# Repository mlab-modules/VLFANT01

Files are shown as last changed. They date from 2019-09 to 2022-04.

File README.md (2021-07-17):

<!--- Name:VLFANT01B: --->
# VLFANT01B
<!--- LongName --->
## VLF antenna interconnection module
<!--- ELongName --->

<!--- Lead --->

<!--- ELead --->

The module is usually used to make a magnetic loop antenna from the UTP pigtail. It is basic antenna for [VLF ionospheric monitoring station](https://github.com/Ionozor/VLFMON01).

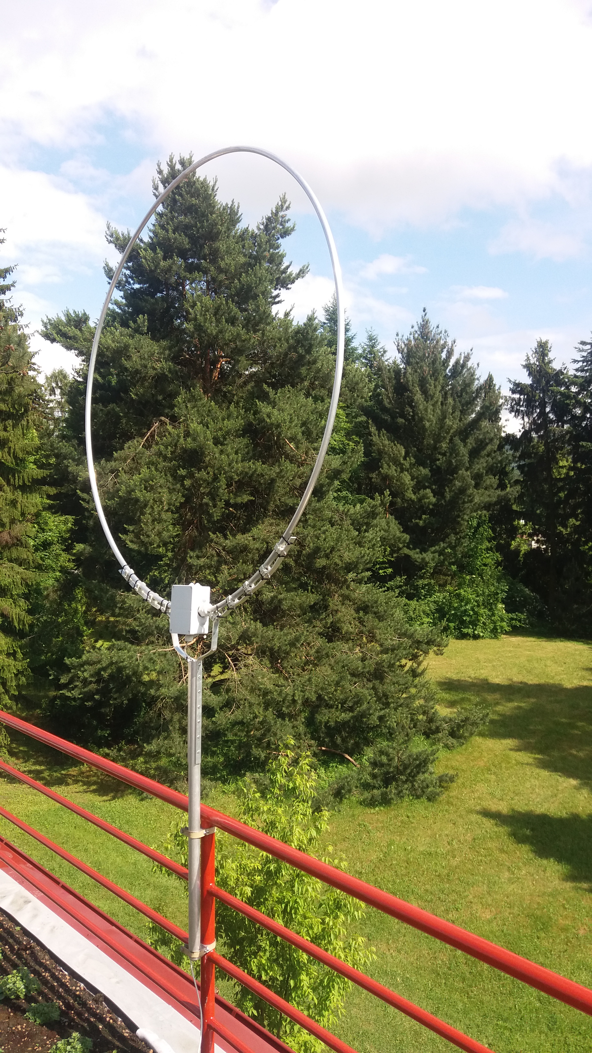
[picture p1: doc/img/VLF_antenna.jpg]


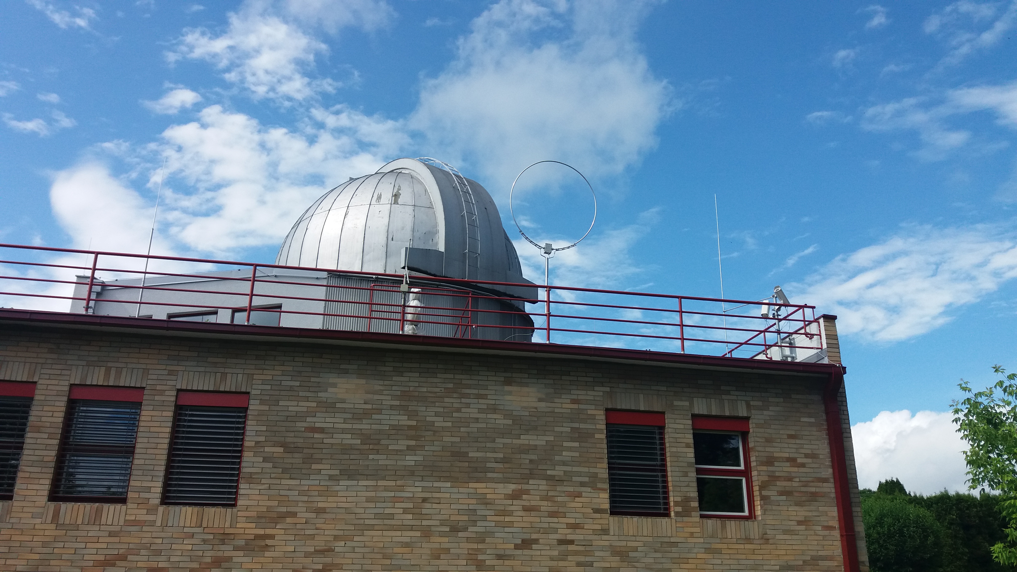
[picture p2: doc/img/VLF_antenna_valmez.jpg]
VLF antenna mounted on Valasske Mezirici observatory


<!--- Description --->
<!--- EDescription --->
<!--- Content --->

## Hardware

The module could be used by multiple ways

### Antenna feed end on MLAB board

This usage case uses only one RJ45 connector populated on board. This connector is used for connection the UTP feed from the antenna.

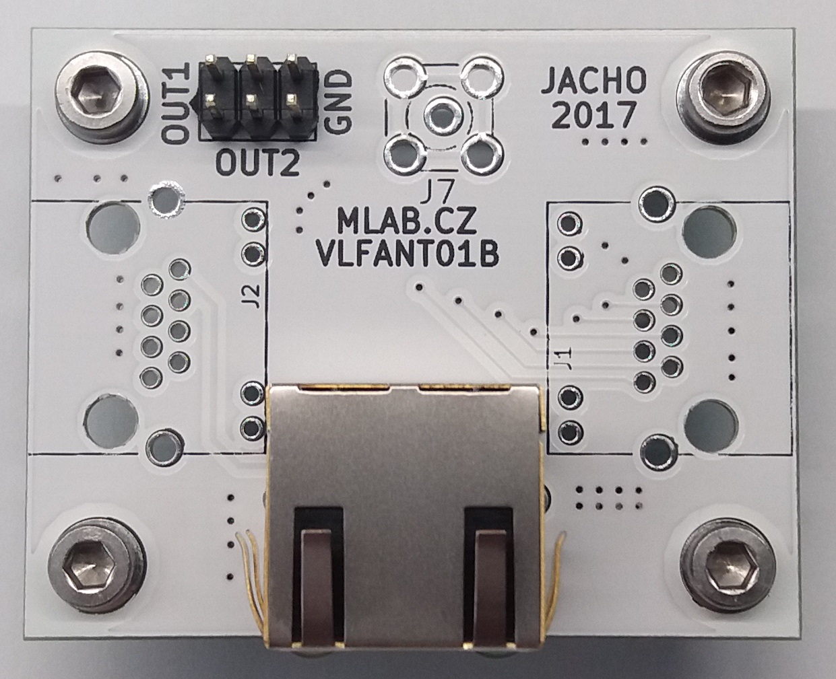
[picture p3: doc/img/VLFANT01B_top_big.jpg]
VLFANT01B


### Antenna connection module

In that situation all three RJ45 connectors are populated on the board. The two are used for connection the antenna loop. The last is used for feeding the signal to the receiver unit.

## VLF antenna construction

The antenna is made from an aluminium tube ring. The parameters of the aluminium tube are not critical. But it is practical to use an tube which allows direct insertion of UTP pigtail including the connectors.
The circumference of the tube ring should match the lengh of UTP cable used. Therefore the example 1.5m circle diameter aproximately match to 5m lenght UTP cable pigtail. In the reality we used the STP (Shilded variant of UTP cable), to minimize possibility of differences between antennas by different shaping of the cable in the tube, which could alter overall capacity, resulting in different resonant frequency. 

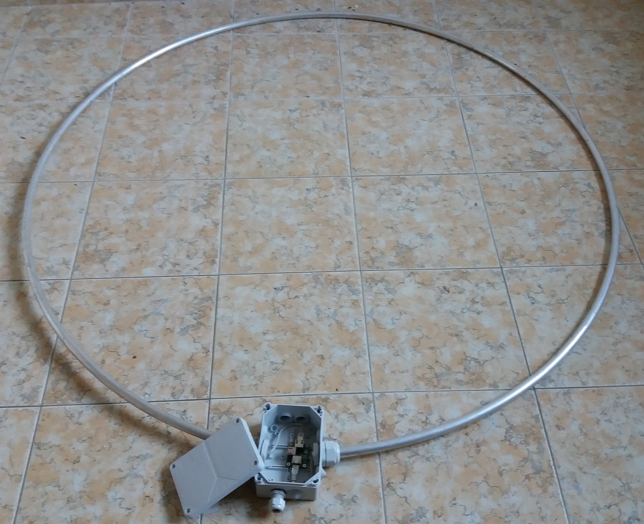
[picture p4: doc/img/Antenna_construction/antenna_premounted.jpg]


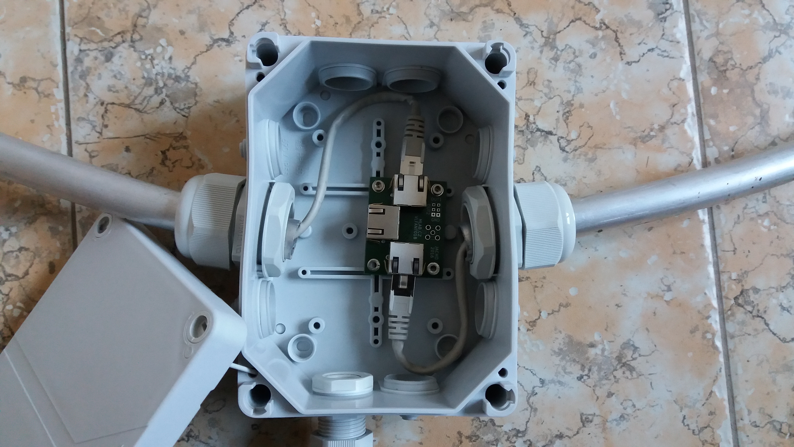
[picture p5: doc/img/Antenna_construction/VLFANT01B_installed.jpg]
VLFANT01B


<!--- EContent --->
<sub><sup> Generated with [MLABweb](https://github.com/MLAB-project/MLABweb). (2019-09-12)</sup></sub>

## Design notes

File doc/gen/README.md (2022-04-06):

# PCB

Board size: 50.29x40.13 mm (1.98x1.58 inches)

- This is the size of the rectangle that contains the board
- Thickness: 1.6 mm (63 mils)
- Material: FR4
- Finish: HAL
- Layers: 2
- Copper thickness: 35 µm

Solder mask: TOP / BOTTOM

- Color: Green

Silk screen: TOP / BOTTOM

- Color: White

# Important sizes

Clearance: 0.2 mm (8 mils)

Track width: 0.2 mm (8 mils)

- By design rules: 0.2 mm (8 mils)

Drill: 0.4 mm (16 mils)

- Vias: 0.4 mm (16 mils) [Design: 0.3 mm (12 mils)]
- Pads: 0.89 mm (35 mils)

Via: 0.8/0.4 mm (31/16 mils)

- By design rules: 0.4/0.3 mm (16/12 mils)
- Micro via: no [0.2/0.1 mm (8/4 mils)]
- Burried/blind via: no

Outer Annular Ring: 0.37 mm (15 mils)

- By design rules: 0.37 mm (15 mils)

Eurocircuits class: 4C

# General stats

Components count: (SMD/THT)

- Top: 0/9 (THT)
- Bottom: 0/0 (NONE)

Defined tracks:

- 0.3 mm (12 mils)
- 0.5 mm (20 mils)
- 0.8 mm (31 mils)
- 0.9 mm (35 mils)
- 1.0 mm (39 mils)
- 1.2 mm (47 mils)
- 1.5 mm (59 mils)
- 2.0 mm (79 mils)

Used tracks:

- 0.2 mm (8 mils) (75) defined: no
- 0.3 mm (12 mils) (37) defined: yes
- 0.5 mm (20 mils) (39) defined: yes

Defined vias:

Used vias:

- 0.8/0.4 mm (31/16 mils) (Count: 47, Aspect: 2.0 A) defined: no

Holes (excluding vias):

- 0.89 mm (35 mils) (6)
- 0.93 mm (37 mils) (36)
- 1.5 mm (59 mils) (1)
- 1.65 mm (65 mils) (6)
- 1.7 mm (67 mils) (4)
- 3.0 mm (118 mils) (4)
- 3.3 mm (130 mils) (6)

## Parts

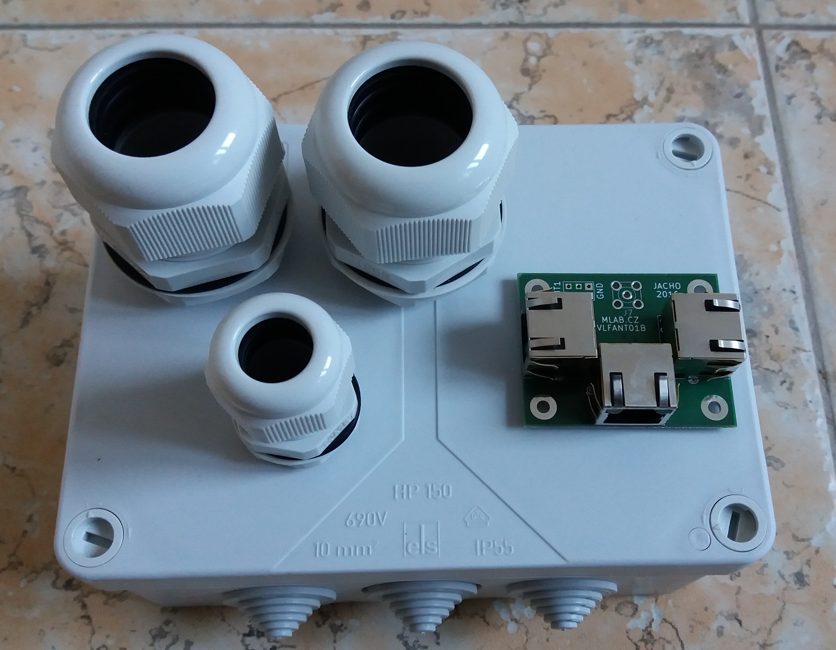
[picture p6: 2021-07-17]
doc/img/Antenna_construction/box_material.jpg

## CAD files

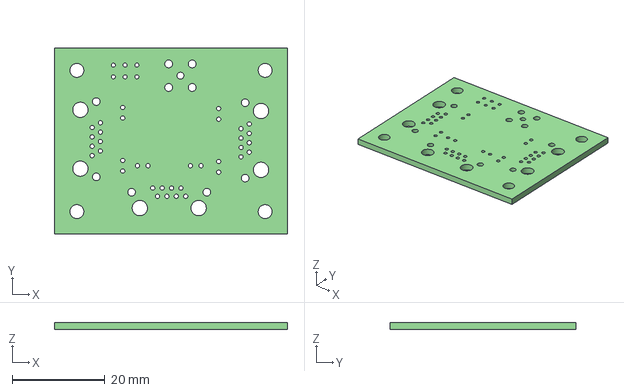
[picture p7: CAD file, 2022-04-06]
doc/gen/VLFANT01B.step
50.3 x 40.1 x 1.60 mm

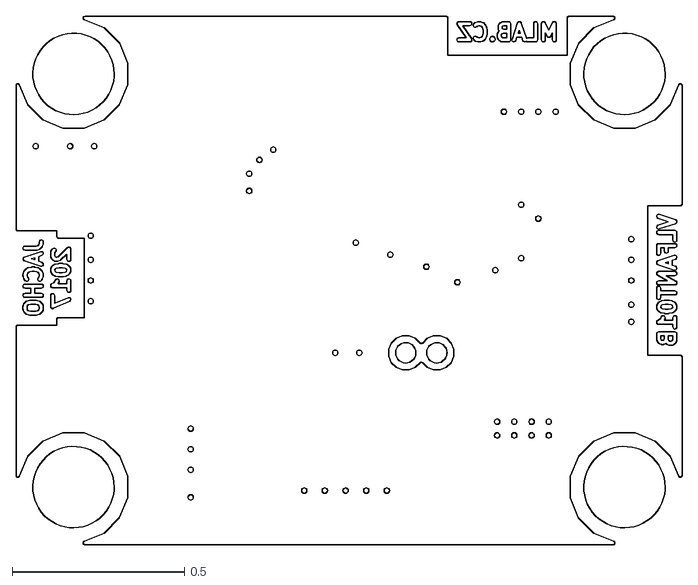
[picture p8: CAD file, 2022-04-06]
doc/gen/dxf/VLFANT01B-B_Cu.dxf
1.93 x 1.53

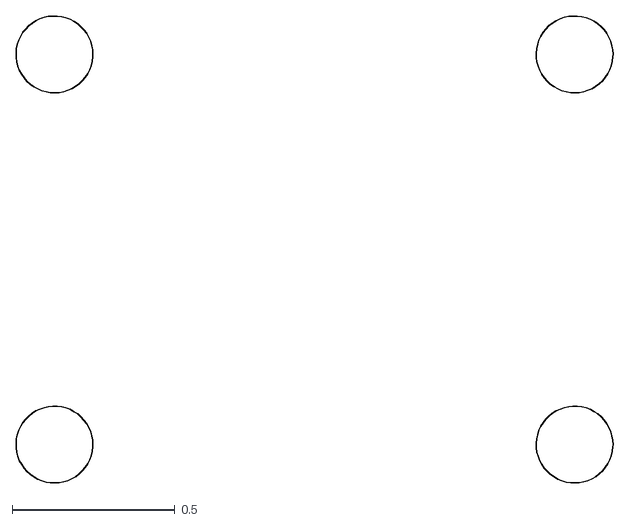
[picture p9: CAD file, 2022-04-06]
doc/gen/dxf/VLFANT01B-F_Adhesive.dxf
1.84 x 1.44

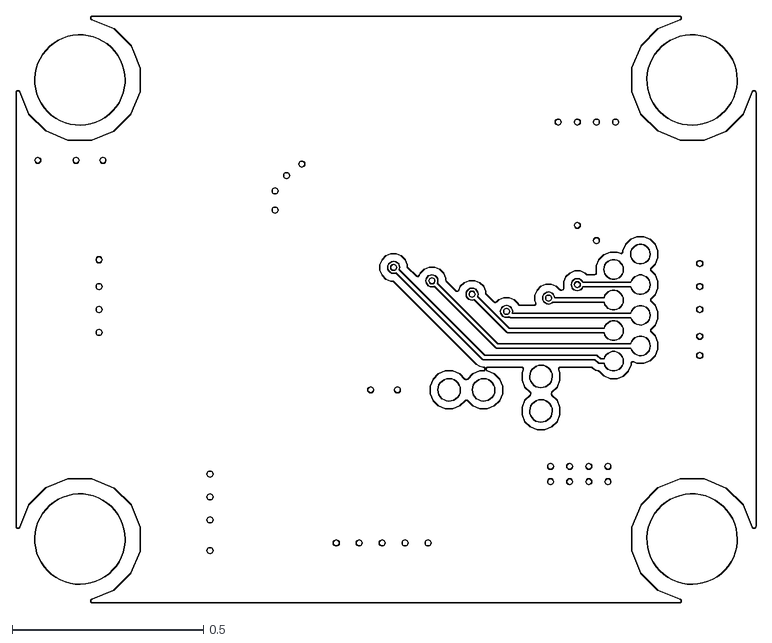
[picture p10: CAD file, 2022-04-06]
doc/gen/dxf/VLFANT01B-F_Cu.dxf
1.93 x 1.53

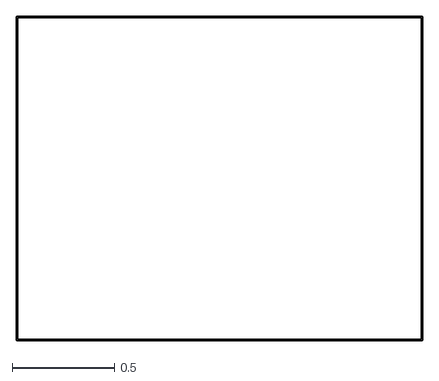
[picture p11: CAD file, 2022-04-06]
doc/gen/dxf/VLFANT01B-Edge_Cuts.dxf
1.99 x 1.59

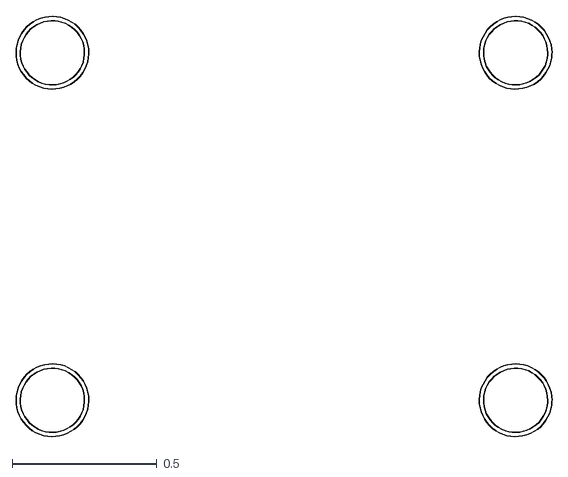
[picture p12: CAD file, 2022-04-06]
doc/gen/dxf/VLFANT01B-User_Comments.dxf
1.85 x 1.45

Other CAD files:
doc/gen/dxf/VLFANT01B-B_Fab.dxf
doc/gen/dxf/VLFANT01B-B_Courtyard.dxf
doc/gen/dxf/VLFANT01B-F_Fab.dxf
doc/gen/dxf/VLFANT01B-User_Eco2.dxf
doc/gen/dxf/VLFANT01B-User_Drawings.dxf
doc/gen/dxf/VLFANT01B-F_Courtyard.dxf
doc/gen/dxf/VLFANT01B-Margin.dxf
doc/gen/dxf/VLFANT01B-User_Eco1.dxf
doc/gen/dxf/VLFANT01B-B_Mask.dxf
doc/gen/dxf/VLFANT01B-B_Paste.dxf
doc/gen/dxf/VLFANT01B-B_Silkscreen.dxf
doc/gen/dxf/VLFANT01B-F_Mask.dxf
doc/gen/dxf/VLFANT01B-F_Paste.dxf
doc/gen/dxf/VLFANT01B-F_Silkscreen.dxf

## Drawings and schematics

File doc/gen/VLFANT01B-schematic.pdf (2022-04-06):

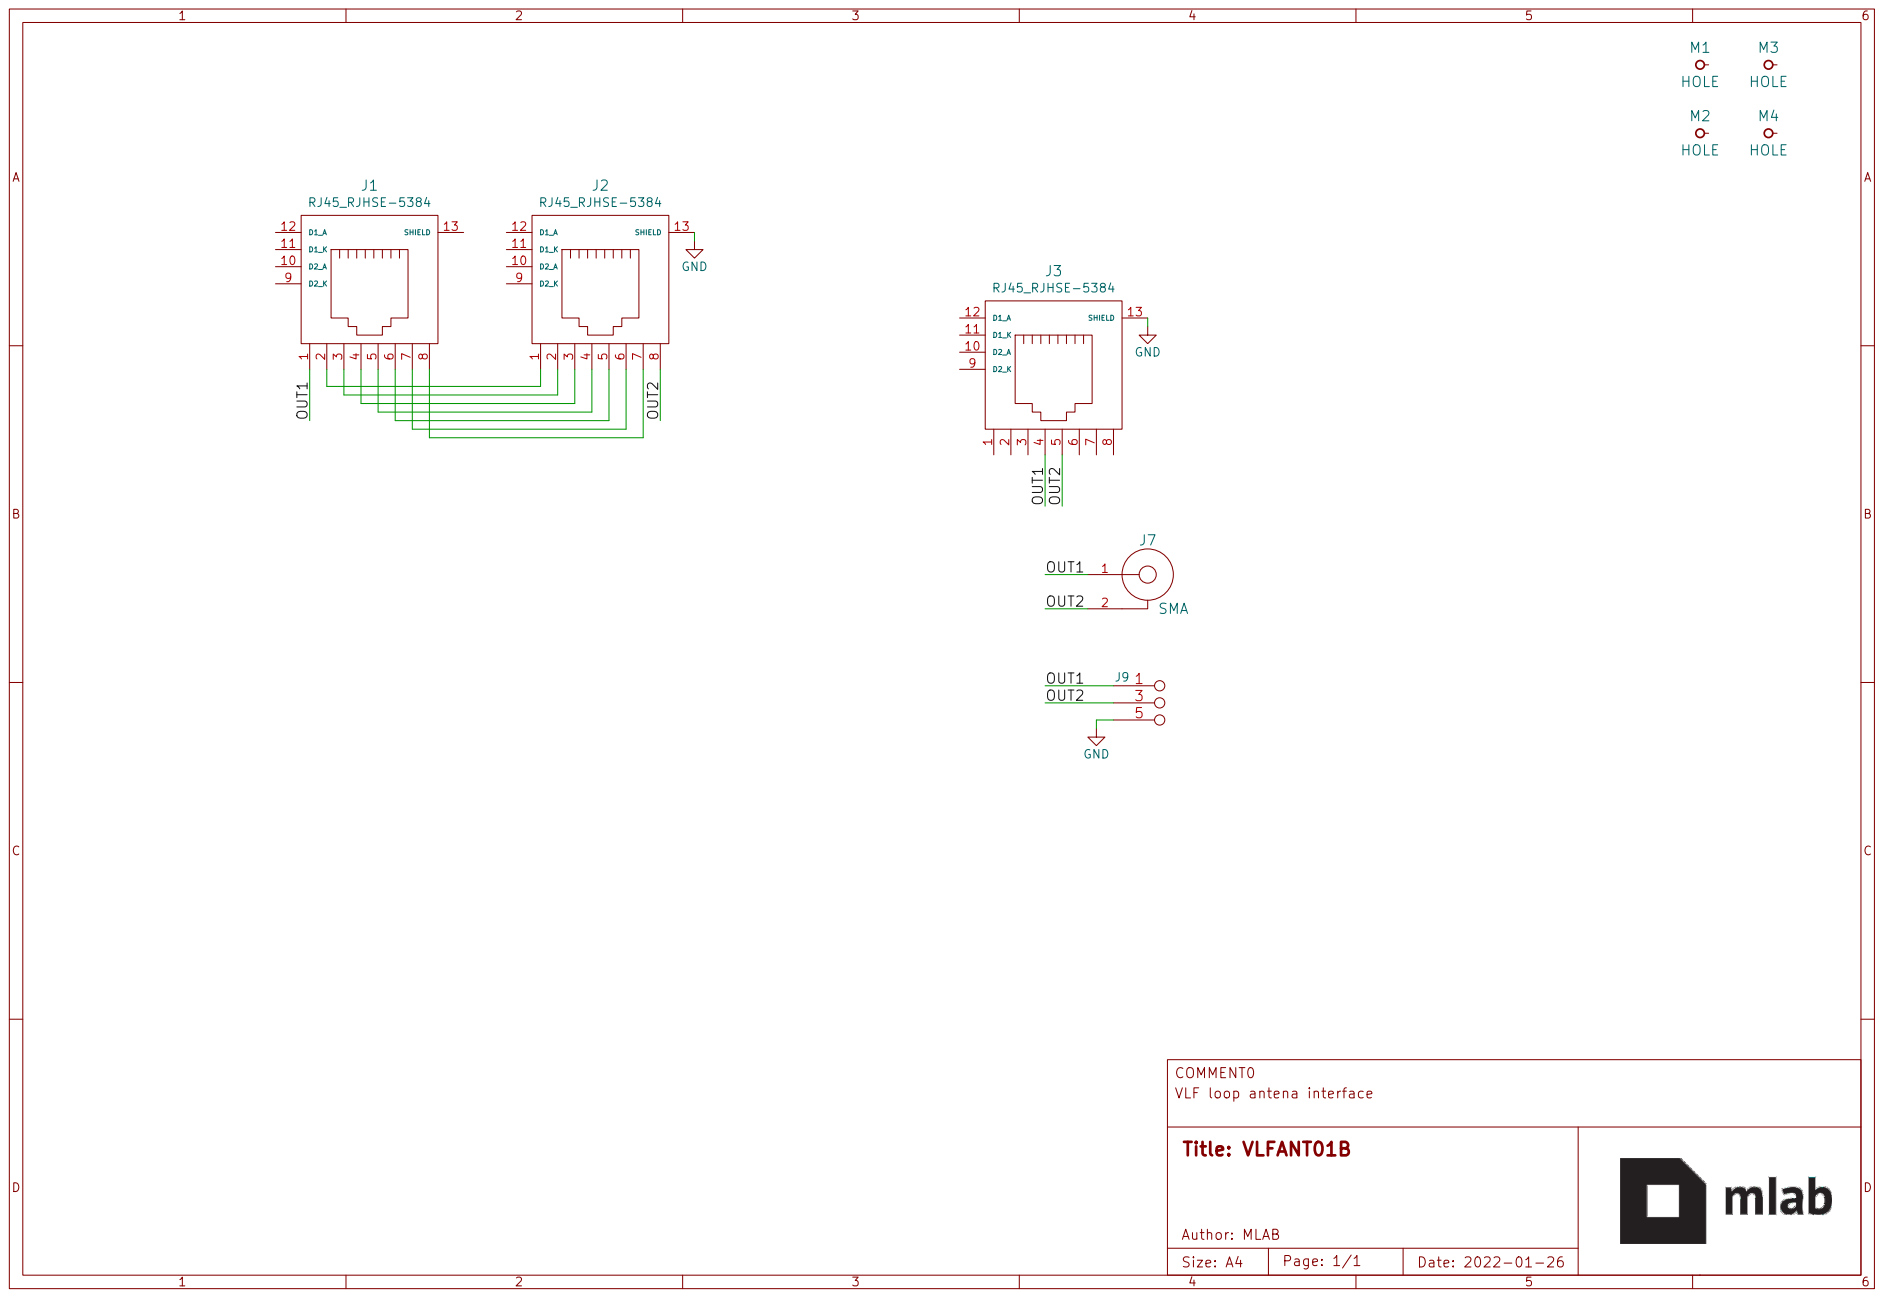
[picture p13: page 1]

COMMENT0 VLF loop antena interface

Size: A4 Page: 1/1 Date: 2022-01-26 Title: VLFANT01B | D Author: MLAB

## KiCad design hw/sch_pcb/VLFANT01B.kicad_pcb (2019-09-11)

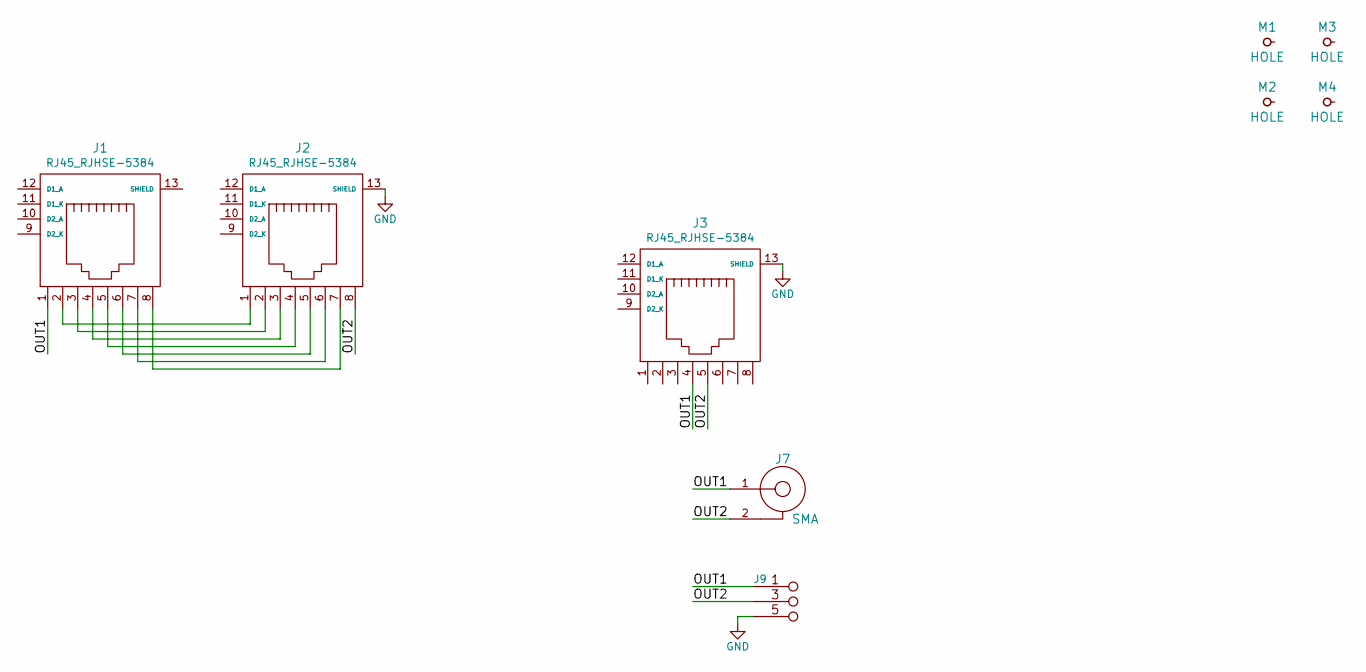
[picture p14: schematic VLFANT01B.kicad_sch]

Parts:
J1, J2, J3: RJ45_RJHSE-5384; RJHSE-5384(RJ45)
J7: SMA; SMA6251A13G50
J9: JUMP_3X2; Straight_2x03
M1, M2, M3, M4: HOLE; MountingHole_3mm

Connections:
/OUT1: J1.1, J3.4, J7.1, J9.1 (2), J9.2
/OUT2: J2.8, J3.5, J7.2, J9.3 (4), J9.4
GND: J2.13 (SHIELD), J3.13 (SHIELD), J9.5 (6), J9.6
unnamed: J1.2, J2.1
unnamed: J1.3, J2.2
unnamed: J1.4, J2.3
unnamed: J1.5, J2.4
unnamed: J1.6, J2.5
unnamed: J1.7, J2.6
unnamed: J1.8, J2.7

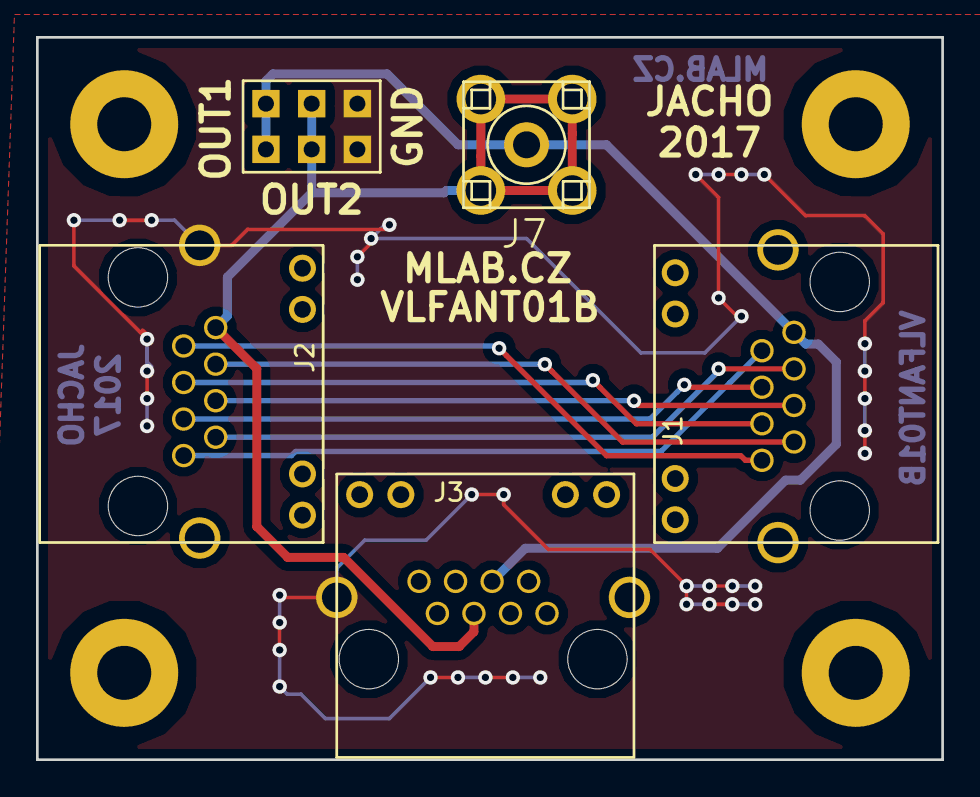
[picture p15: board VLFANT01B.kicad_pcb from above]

Board: 2 copper layers, 50.3 x 40.1 mm, 9 parts (0 on the bottom side), 10 nets.

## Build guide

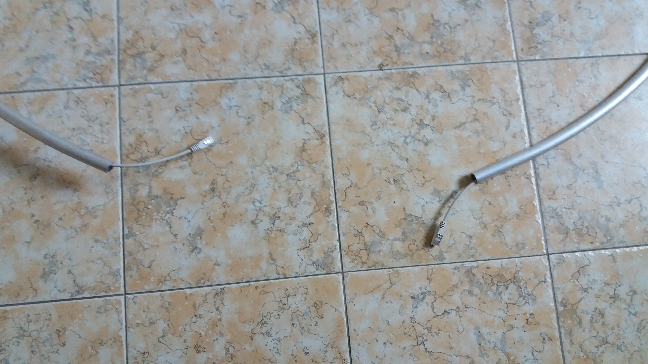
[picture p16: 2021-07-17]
doc/img/Antenna_construction/UTP_cable_ends.jpg

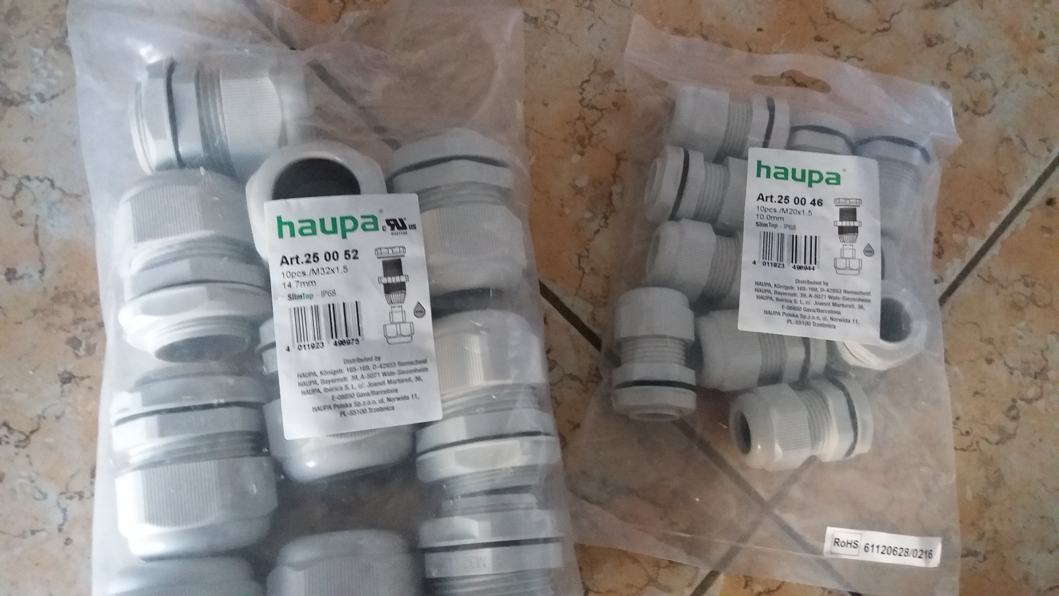
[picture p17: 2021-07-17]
doc/img/Antenna_construction/cable_bushing.jpg

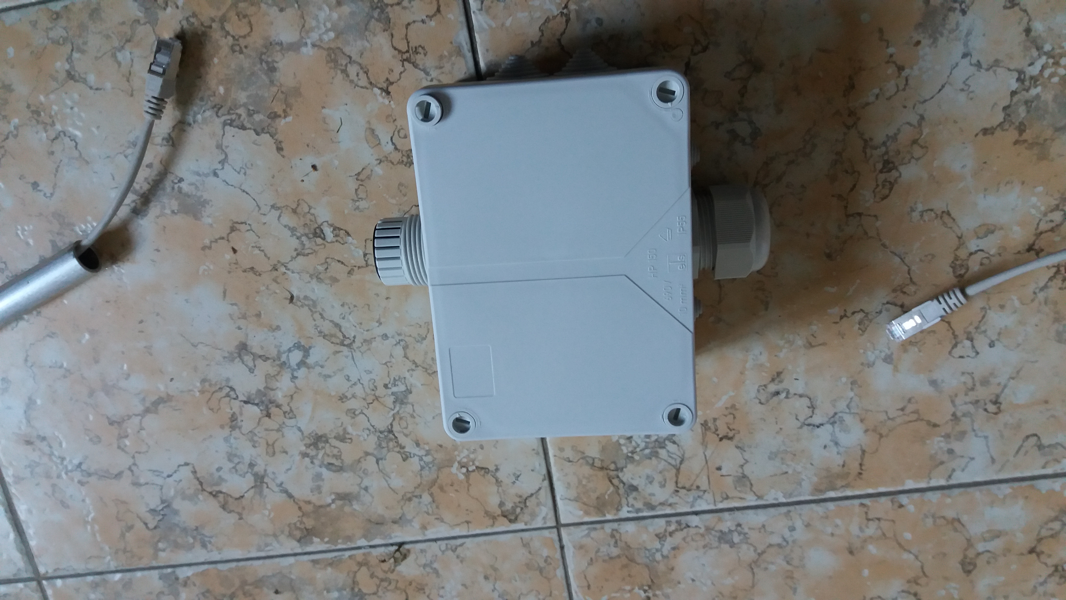
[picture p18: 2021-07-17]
doc/img/Antenna_construction/box_bushing_preinstall.jpg

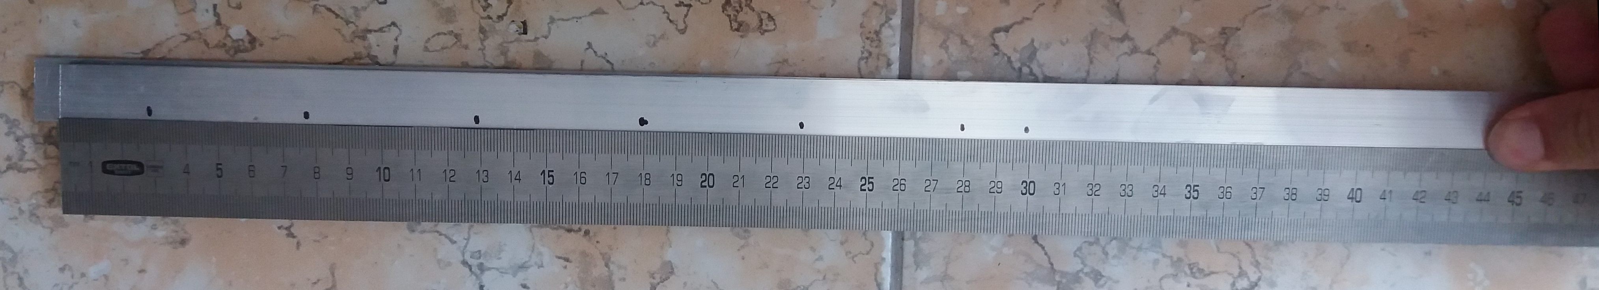
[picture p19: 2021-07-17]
doc/img/Antenna_construction/mounting_strip1.jpg

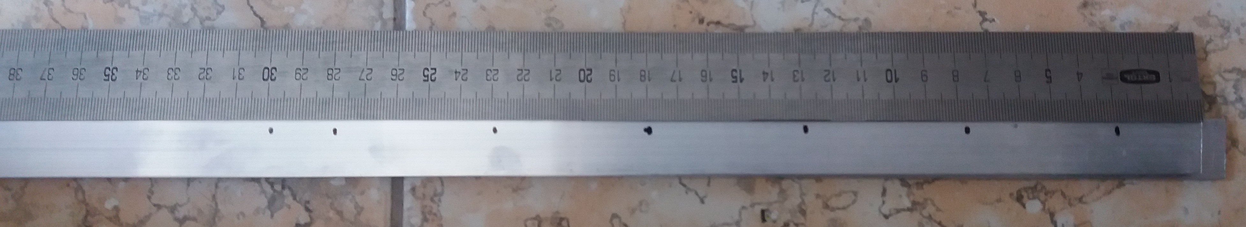
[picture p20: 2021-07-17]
doc/img/Antenna_construction/mounting_strip2.jpg

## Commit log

2019-09-11 Commiting module from VLFMON01A ionospheric monitoring station.
    [VLFANT01B-B.Cu.gbr, VLFANT01B-B.Mask.gbr, VLFANT01B-Edge.Cuts.gbr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]
2019-09-12 Odebrání modulu pro umožnění vytvoření modulu v databázi.
    [VLFANT01B-B.Cu.gbr, VLFANT01B-B.Mask.gbr, VLFANT01B-Edge.Cuts.gbr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]
2019-09-12 [MLABweb] Documentation edits; VLFANT01B
    [VLFANT01B.kicad_pcb, VLFANT01B.sch]
2019-09-12 Vraceni zdrojových souborů po vytvoření modulu v databázi.
    [VLFANT01B-B.Cu.gbr, VLFANT01B-B.Mask.gbr, VLFANT01B-Edge.Cuts.gbr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]
2021-07-17 Adding basic documentation to the antenna construction.
2022-01-26 Update project to new KiCAD 6 format. Regenerating the schematic PDF.
    [VLFANT01B.kicad_sch, VLFANT01B.sch]
2022-04-06 Update actions products
    [VLFANT01B-B_Adhesive.dxf, VLFANT01B-B_Courtyard.dxf, VLFANT01B-B_Cu.dxf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]
